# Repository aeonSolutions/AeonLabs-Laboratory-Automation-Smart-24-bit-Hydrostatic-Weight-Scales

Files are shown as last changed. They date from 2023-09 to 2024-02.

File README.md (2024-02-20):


  
 
 

<a href="https://trackgit.com">
trackgit-views
</a>




[](https://www.buymeacoffee.com/migueltomas)

[PCB-Prototyping-Catalogue](https://github.com/aeonSolutions/PCB-Prototyping-Catalogue)  >>  [Laboratory Automation](https://github.com/aeonSolutions/PCB-Prototyping-Catalogue/tree/main/Laboratory%20Automation)  >> Wieght Scales >> Smart 24-bit Hydrostatic Weight Scale

<br>

# 24-bit Smart data Acquisiton SDAD for Weight Measurments

This is a 24-bit S.D.A.D. weight scale capable to do hydrostatic weight measurments up to 20Kg. 

<p align="center">
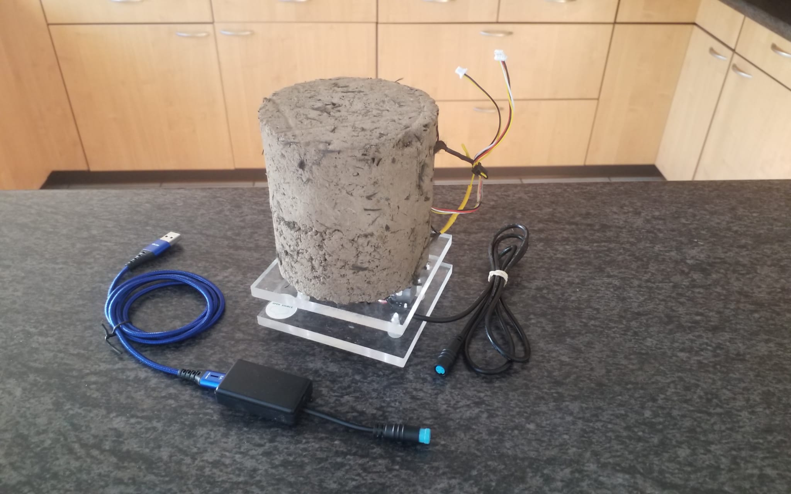
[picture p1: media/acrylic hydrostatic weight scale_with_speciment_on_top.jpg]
    
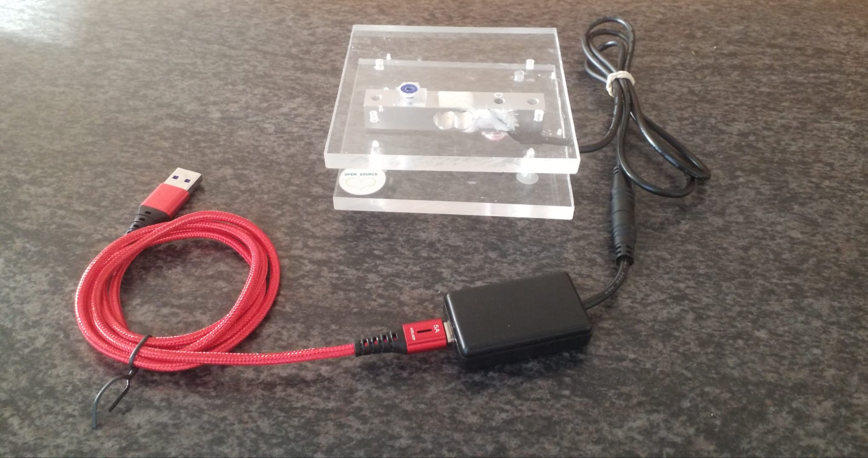
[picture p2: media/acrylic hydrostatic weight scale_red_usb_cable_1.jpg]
     
</p>

<br>

## Parts List
 - [S.D.A.D. hardware electronics](http://www.tindie.com/stores/aeonlabs)
 - [Plexiglass Clear Acrylic Board](https://s.click.aliexpress.com/e/_Ddi8Lh5)
 - [Load Cell HX711 ](https://s.click.aliexpress.com/e/_DBjevT1)
 - [aluminum flat hex socket countersunk head screw size M4 20mm](https://www.aliexpress.com/item/32964202588.html?spm=a2g0o.order_list.order_list_main.4.f3a61802ivrUvG)
 - [aluminum flat hex socket countersunk head screw size M5 20mm](https://www.aliexpress.com/item/32964202588.html?spm=a2g0o.order_list.order_list_main.4.f3a61802ivrUvG)
 - [connector Cable M8 waterproof 4-pin](https://s.click.aliexpress.com/e/_DCR6iBd)
 - [USB-C cable](https://s.click.aliexpress.com/e/_De4Q32X)

<br>

## Compatibility

<p align="center">
 <a href"https://www.apple.com/shop/accessories/all/homekit">

 </a>
<a href="https://home.google.com"> 
 
 </a>
<a href="https://www.home-assistant.io">  
 
 </a>
<a href="https://csa-iot.org/all-solutions/matter/">  
 
 </a>
<a href="https://csa-iot.org/all-solutions/matter/">  
 
 </a>
</p>

<br>

## What one additionally needs
- [USB to UART/USB TTL firmware burner for 5V and 3.3V MCUs ](https://github.com/aeonSolutions/PCB-Prototyping-Catalogue/blob/main/DIY-Maker/README.md)
- [Upgradable ESP32 MCU](https://github.com/aeonSolutions/AeonLabs-Upgradable-MCU-ESP32)

<br />
<br />

**Get a Notification on every PCB update**

| [](https://www.tindie.com/stores/aeonlabs/) | You can fill in your [email here (Google form)](https://docs.google.com/forms/d/e/1FAIpQLScErMgQYRdA-umvCjvTPPrCO7Lg1QYowTxb7vfa8cTfrcPEAA/viewform?usp=pp_url) and I'll send a reminder when a new PCB prototype is made available here or a new revision for an existing PCB. Stay tuned! |
|---|---|

<br>
<br>

## Author

You can get in touch with me on my LinkedIn Profile:

#### Miguel Tomas



You can also follow my GitHub Profile to stay updated about my latest projects: 

**Hire me on Fiverr**

If you like my work here and are looking to design and deploy your own smart device you can hire me on:

- [Fiverr](https://www.fiverr.com/s/GjmPxe). The price starts at $25
- [Guru](https://www.guru.com/freelancers/miguel-tomas)
  
<br>

### Be supportive of my dedication and work towards technology education and buy me a cup of coffee
The PCB Desgin Files i provide here for anyone to use are free. If you like this Smart Device or use it, please consider buying me a cup of coffee, a slice of pizza or a book to help me study, eat and think new PCB design files.

[](https://www.buymeacoffee.com/migueltomas)

<br />

### Make a donation on Paypal
Make a donation on paypal and get a TAX refund*.

(http://paypal.me/mtpsilva)

<br>

### Support all these open hardware projects and become a patreon  
Liked any of my PCB KiCad Designs? Help and Support my open work to all by becomming a LDAD Patreon.
In return I will give a free PCB design in KiCad to all patreon supporters. To learn more go to patreon.com. Link below.

(https://www.patreon.com/ldad)

<br />
<br />

______________________________________________________________________________________________________________________________
### License

Before proceeding to download any of AeonLabs software solutions for open-source development and/or PCB hardware electronics development make sure you are choosing the right license for your project. See [AeonLabs Solutions for Open Hardware & Source Development](https://github.com/aeonSolutions/PCB-Prototyping-Catalogue/wiki/AeonLabs-Solutions-for-Open-Hardware-&-Source-Development) for more information.

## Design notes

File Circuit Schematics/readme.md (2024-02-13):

[PCB-Prototyping-Catalogue](https://github.com/aeonSolutions/PCB-Prototyping-Catalogue)  >>  [Laboratory Automation](https://github.com/aeonSolutions/PCB-Prototyping-Catalogue/tree/main/Laboratory%20Automation)  >> Wieght Scales >> Smart 24-bit Hydrostatic Weight Scale

<div align="right">
 <a href="https://github-com.translate.goog/aeonSolutions/AeonLabs-AI-Volvo-MKII-Open-Hardware/wiki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">Change language</a>  <br>
Last change 15-02-2024
</div>

<br>

This folder contains the circuit schematic for the Smart 24-bit Hydrostatic Weight Scale used on my Open Science projects. Each KiCad project is available with a [creative commons share alike non-commercial license](https://creativecommons.org/licenses/by-nc-sa/4.0/deed.en) . If you like it and use it on your own hardware designs please support this project, [click here](https://github.com/sponsors/aeonSolutions) to learn how. <br> Thank you 🙏. 

### Support all these open hardware projects and become a GitHub sponsor  
Liked any of my PCB KiCad Designs? Help and Support my open work to all by becoming a GitHub sponsor.

<p align="center">
    <a href="">
        
    </a>
    <a href="https://github.com/sponsors/aeonSolutions">
        
    </a>
</p>

#

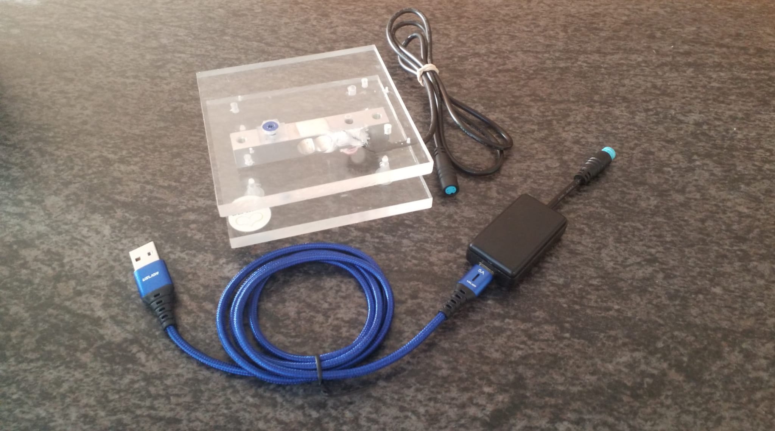
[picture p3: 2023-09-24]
media/acrylic hydrostatic weight scale_3.jpg

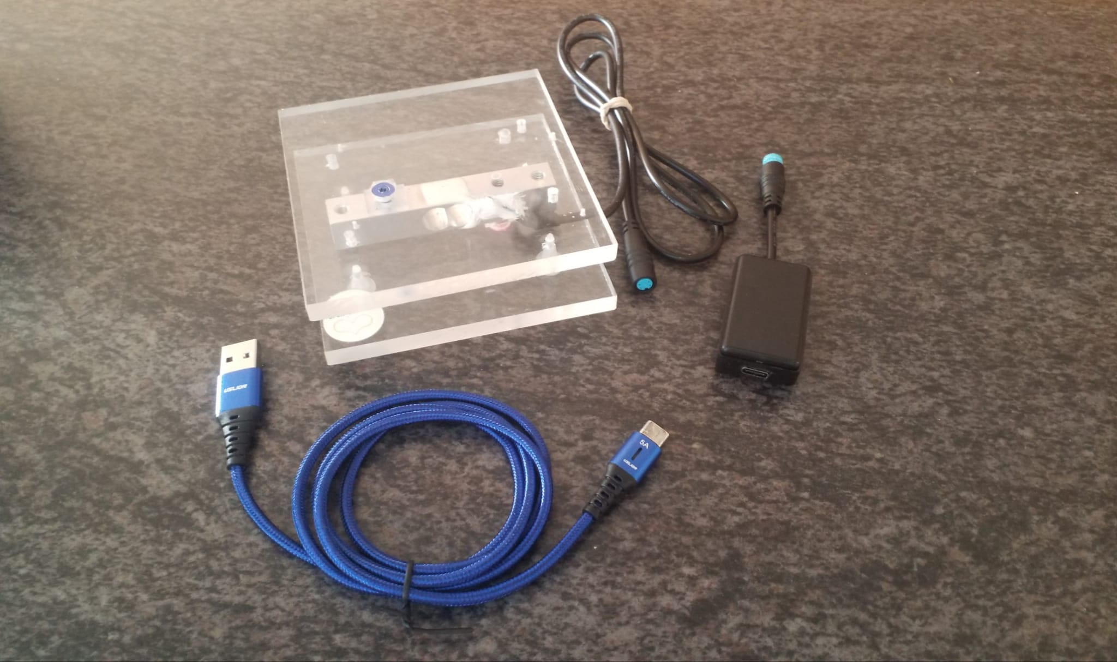
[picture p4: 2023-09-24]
media/acrylic hydrostatic weight scale_2.jpg

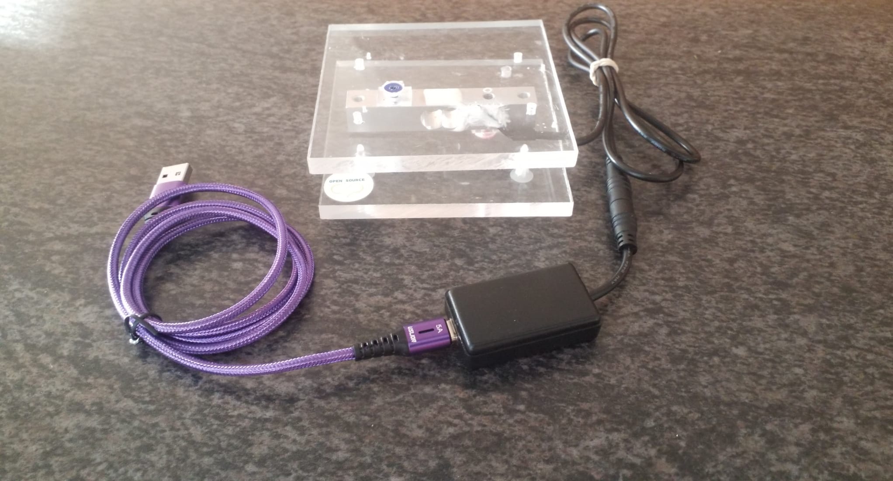
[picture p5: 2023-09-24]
media/acrylic hydrostatic weight scale_violet_usb_cable_1.jpg

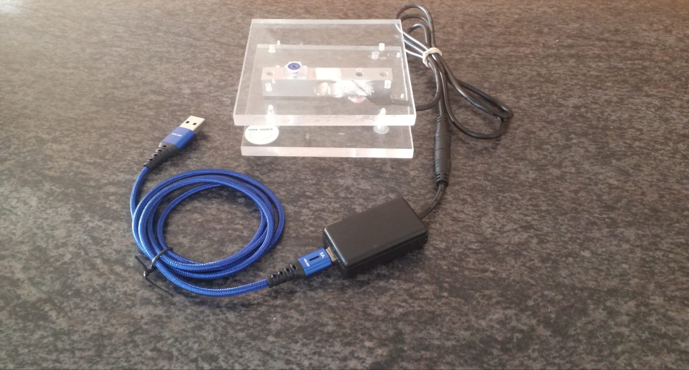
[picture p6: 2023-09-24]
media/acrylic hydrostatic weight scale_4.jpg

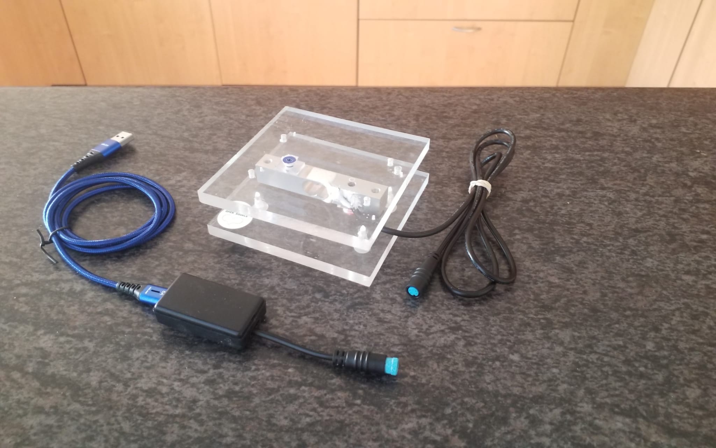
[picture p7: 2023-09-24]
media/acrylic hydrostatic weight scale_1.jpg

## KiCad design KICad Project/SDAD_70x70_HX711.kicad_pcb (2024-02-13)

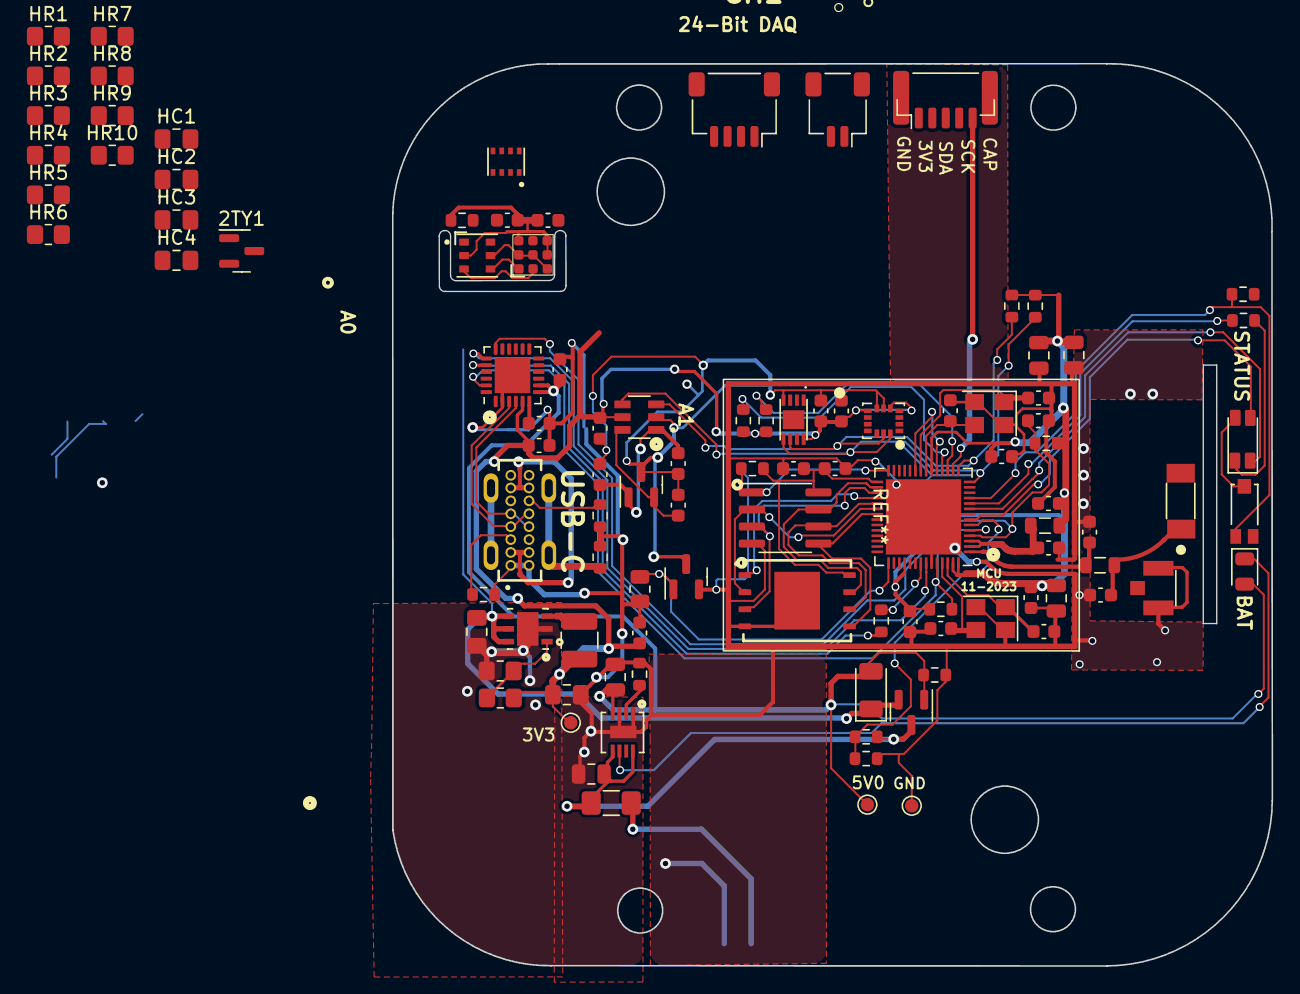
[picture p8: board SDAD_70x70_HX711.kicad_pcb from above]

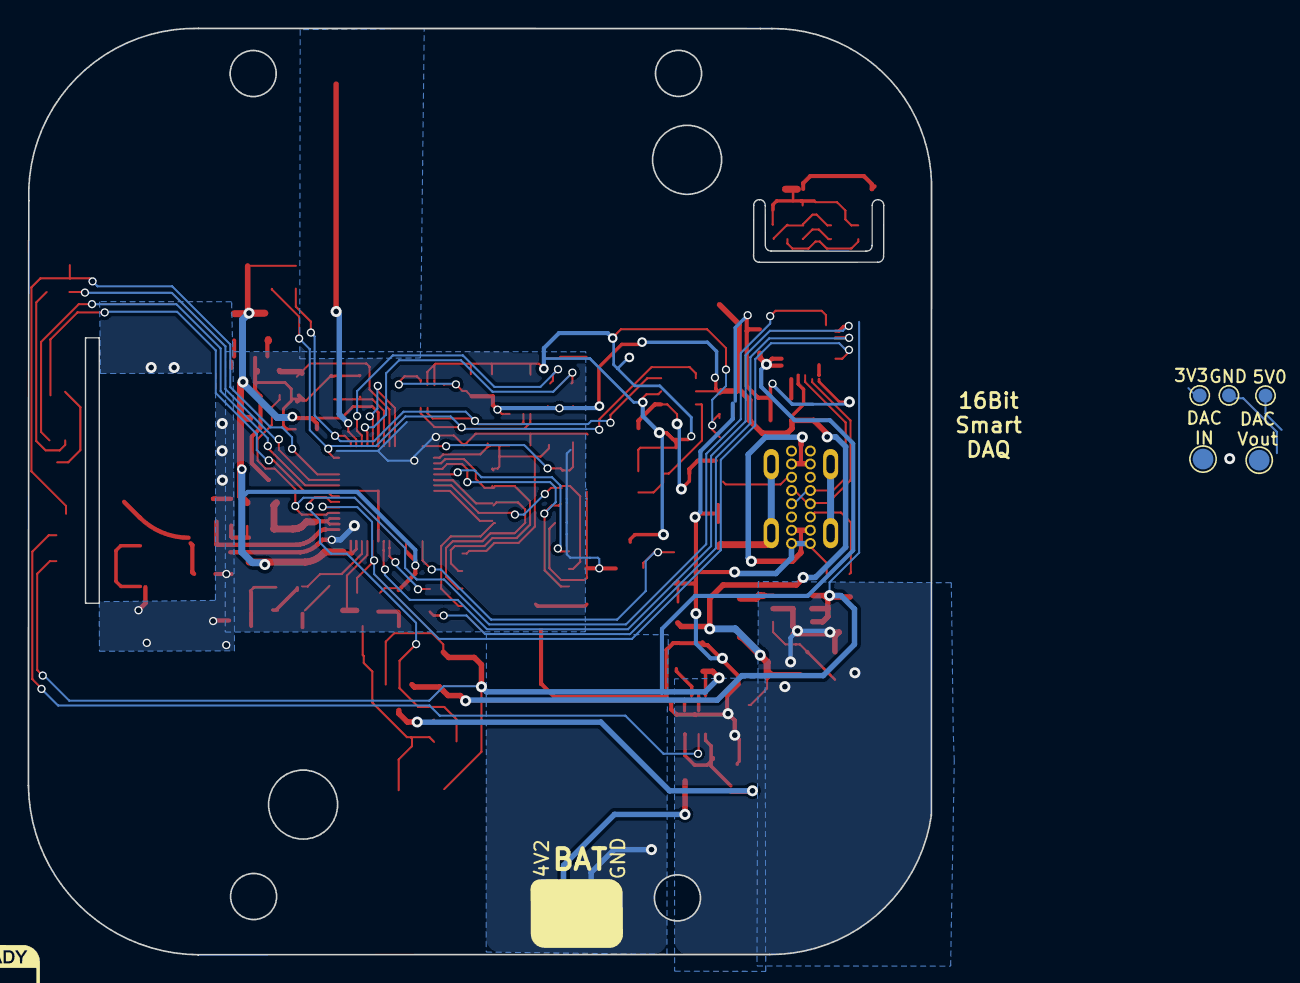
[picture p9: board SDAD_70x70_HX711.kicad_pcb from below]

Board: 2 copper layers, 65.4 x 67.1 mm, 108 parts (4 on the bottom side), 64 nets.

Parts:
2TY1: S8550; SOT-23
ADS1100_CH2: ADS1100A0IDBVR; ADS1100 16-bit ADC SOT95P280X145-6N
ADS1100_CH_C3: 33-100pF; C_0603_1608Metric
ADS1100_CH_C4: 100nF; C_0603_1608Metric
ATSHA_C1: 100nF; C_0603_1608Metric
AUR1: AUR9718x_DFN_3x3mm_6_pin; AUR9718 ST1S09 SON95P300X300X100-7N
AUR_C1: 22uF; C_0805_2012Metric_Pad1.18x1.45mm_HandSolder
AUR_C2: 4.7uF; C_0805_2012Metric_Pad1.18x1.45mm_HandSolder
AUR_R1: 75k; R_0805_2012Metric_Pad1.20x1.40mm_HandSolder
AUR_R2: 24k; R_0805_2012Metric_Pad1.20x1.40mm_HandSolder
AUR_l1: 3.3uF; L_1210_3225Metric
BAT_FUSE1: Polyfuse; Fuse_1206_3216Metric_Pad1.42x1.75mm_HandSolder
BAT_SENSE_R1, BAT_SENSE_R2: 100k; R_0603_1608Metric
BMPR1: 10k; R_0603_1608Metric
CHC1, CHC2, CHC3: 1uF; C_0603_1608Metric
CN3065_C2: 4.7uF; C_0805_2012Metric
CN3065_R1: 1K8; R_0603_1608Metric
CN3065_STDBY_LED1: LED; LED_0805_2012Metric
CN3965_C1: 22uF; C_0805_2012Metric
DMP1045U_1: DMP1045U; SOT-23
DMP1045_R1: 10K; R_0603_1608Metric
DMP1045_SCHOT1: D_Schottky; D_1206_3216Metric
ENS_C1: 1uF; C_0603_1608Metric
ENS_C2: 100nF; C_0603_1608Metric
EPS1: ESP32-PSRAM_LY68L6400S; SOIC-8_3.9x4.9mm_P1.27mm
ESP32S1: ESP32-S3; QFN-56-1EP_7x7mm_P0.4mm_EP5.6x5.6mm
ESP32_SHIELD1: RFShield_OnePiece; ESP32-S3 GND Shield
ESP_FLASH1: W25Q128JVS; WSON8 FLASH SPI SON127P800X600X80-9N
E_DTR_R1: 10k; R_0603_1608Metric
E_LNA_ANT1: AN9520; CrossAir CA-C03
E_LNA_ANT2: U.FL-R-SMT(01); RF Antenna IPEX SMD PCB HRS_U.FL-R-SMT(01)
E_LNA_C1, E_LNA_C2: 2.7pF; C_0603_1608Metric
E_LNA_l1: 1.8nH 5%; L_0805_2012Metric
E_RTS_C1: 100nF; C_0603_1608Metric
E_RTS_R1: 10k; R_0603_1608Metric
E_SPI_C1: 1uF 10% 50V; C_0603_1608Metric
E_SPI_C2: 100nF 10% 16V; C_0603_1608Metric
E_UART_TX_1: 499R; R_0603_1608Metric
E_VDDA_C1: 100nF; C_0603_1608Metric
E_VDDA_C2: 1uF 10% 50V; C_0805_2012Metric
E_VDD_3_C1, E_VDD_3_C2: 10uF 20% 6.3V; C_0805_2012Metric
E_VDD_3_C3, E_VDD_3_C4: 100nF 10% 16V; C_0603_1608Metric
E_VDD_CPU_C1: 100nF 10% 16V; C_0603_1608Metric
E_VDD_L1: 12nH 5%; L_0805_2012Metric
E_VDD_RTC_C1: 100nF 10% 16V; C_0603_1608Metric
E_XTAL32_1: 32.768Mhz 22pF+-10PPM; Crystal_SMD_3225-4Pin_3.2x2.5mm
E_XTAL32_C1, E_XTAL32_C2, E_XTAL40_C1, E_XTAL40_C2: 22pF 5% 50V; C_0603_1608Metric
E_XTAL40_1: 40Mhz 22pF+-10PPM; Crystal_SMD_3225-4Pin_3.2x2.5mm
ExtSWBAT_PLUG2: Conn_01x03_Female; JST_SH_BM03B-SRSS-TB_1x03-1MP_P1.00mm_Vertical
HC1: 10pF; C_0805_2012Metric_Pad1.18x1.45mm_HandSolder
HC2, HC3, HC4: 0.1pF; C_0805_2012Metric_Pad1.18x1.45mm_HandSolder
HR1, HR2, HR9, HR10: 2k2; R_0805_2012Metric_Pad1.20x1.40mm_HandSolder
HR3, HR4, HR7, HR8: 100R; R_0805_2012Metric_Pad1.20x1.40mm_HandSolder
HR5: 18k4; R_0805_2012Metric_Pad1.20x1.40mm_HandSolder
HR6: 8.4k; R_0805_2012Metric_Pad1.20x1.40mm_HandSolder
HXC2: 2.2uF; C_0603_1608Metric
I2C1: I2C6; JST_SH_SM04B-SRSS-TB_1x04-1MP_P1.00mm_Horizontal
I2C_SCL_R2, I2C_SDA_R1, I2C_SDA_R2, I2C_SDA_R2#2: 10k; R_0603_1608Metric
IC_ENS1: ENS160 Gas Semsor
IMU1: LSM6DS3; LSM6DS3 Motion Sensor PQFN50P300X250X86-14N
IMUC1: 100nF; C_0603_1608Metric
J2: USB4120-03-C_REVA; USB-C Vertical GCT_USB4120-03-C_REVA
LED1: LED_GBRC; LED_1206_3210_RGB_Metric
LR1: 330R; R_0603_1608Metric
MTRR1: 10k; R_0805_2012Metric
MTRT1: NPN; SOT-23
PLUG2: PLUG2; JST_SH_BM05B-SRSS-TB_1x05-1MP_P1.00mm_Vertical
PSRAM_R1: 100K; R_0603_1608Metric
PWOUT3V1: Screw_Terminal_01x02; JST_SH_SM02B-SRSS-TB_1x02-1MP_P1.00mm_Horizontal
TMPR1: 10K; R_0603_1608Metric
TP1, TP1#2: VIN; TestPoint_Pad_D1.0mm
TP2, TP2#2: VOut; TestPoint_Pad_D1.0mm
TP3, TP3#2: GND; TestPoint_Pad_D1.0mm
U1: MCP1525-TT; SOT-23
U2: ATSHA204A-MAHDA-T; ATSHA204A-MAHDA-T UDFN-8
U3: Battery_charger_CN3065_QFN8; QFN8 3.1x2.9mm QFNn-8 3x3 SON80P400X400X100-9N
U4: AHT20; AHT20 HT Sensor PSON100P300X300X110-6N
U5: CH9102F
U6: TEMT6000; TEMT6000-SEN
U7: BMP280; XDCR_BMP280
USB_PLUG_R2, USB_PLUG_R4: 5k1; R_0603_1608Metric
USB_PLYG_R1: 150K; R_0603_1608Metric
VOLTAGE_REF_C1, VOLTAGE_REF_C2: 100nF; C_0603_1608Metric

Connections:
3V3: 2TY1.2 (E), ADS1100_CH2.5 (VDD), ADS1100_CH_C4.2, ATSHA_C1.2, AUR_C1.1, AUR_R1.1, AUR_l1.1, BMPR1.2, CHC3.1, ENS_C1.2, ENS_C2.2, ESP32S1.20 (VDD3P3_RTC), ESP32S1.46 (VDD3P3_CPU), ESP32S1.55 (VDDA), ESP32S1.56 (VDDA), E_DTR_R1.1, E_RTS_R1.1, E_VDDA_C1.2, E_VDDA_C2.2, E_VDD_3_C1.1, E_VDD_3_C2.1, E_VDD_3_C3.1, E_VDD_CPU_C1.1, E_VDD_L1.1, E_VDD_RTC_C1.1, HXC2.2, I2C_SCL_R2.1, I2C_SDA_R1.2, I2C_SDA_R2.1, I2C_SDA_R2#2.2, IC_ENS1.4 (VDD), IC_ENS1.5 (VDDIO), IC_ENS1.7 (CS), IMU1.5 (VDDIO), IMU1.8 (VDD), IMUC1.2, LED1.4 (K), PLUG2.2, TP2.1, TP2#2.1, U2.8 (VCC), U4.2 (VDD), U5.5 (VIO), U6.COLLECTOR, U7.6 (VDDIO), U7.8 (VDD)
3V3_PLUG: ADS1100_CH2.1 (VIN+), ADS1100_CH_C3.2, U1.1 (Vin), VOLTAGE_REF_C1.2
A+: HR1.2, HR4.2, I2C1.3
A-: HR2.2, HR3.2, I2C1.4
B+: HR7.2, HR9.2, I2C1.1
B-: HR8.2, HR10.1, I2C1.2
BAT_SENSE_IO21: BAT_SENSE_R1.1, BAT_SENSE_R2.2, ESP32S1.6 (GPIO1/ADC1_CH0)
CAPACITIVE_SENSOR_IO11: ESP32S1.16 (GPIO11/ADC2_CH0), PLUG2.5
CHIP_EN: ESP32S1.4 (CHIP_PU/RESET), E_RTS_C1.2, E_RTS_R1.2, U5.18 (CTS)
DAC_CALIBRATION: ESP32S1.19 (GPIO14/ADC2_CH3), ESP32S1.23 (GPIO17/ADC2_CH6/DAC_2)
ESP_GPIO0_BOOT-DTR: ESP32S1.5 (GPIO0/BOOT), ESP32S1.52 (GPIO46), E_DTR_R1.2, U5.23 (DTR)
GND: AUR1.2 (GND), AUR1.7 (GND), AUR_C1.2, AUR_C2.2, AUR_R2.2, BAT_SENSE_R1.2, CHC1.2, CHC2.1, CHC3.2, CN3065_C2.1, CN3065_R1.1, CN3965_C1.1, DMP1045_R1.2, EPS1.4 (VSS), ESP32S1.8 (GPIO3/ADC1_CH2), ESP32S1.51 (GPIO45), ESP32S1.57 (GND), ESP32_SHIELD1.1 (Shield), ESP_FLASH1.4 (GND), ESP_FLASH1.9 (GND), E_LNA_ANT2.1 (GND), E_LNA_ANT2.2 (GND), E_LNA_C1.2, E_LNA_C2.2, E_RTS_C1.1, E_SPI_C1.2, E_SPI_C2.2, E_VDDA_C1.1, E_VDDA_C2.1, E_VDD_3_C1.2, E_VDD_3_C2.2, E_VDD_3_C3.2, E_VDD_3_C4.2, E_VDD_CPU_C1.2, E_VDD_RTC_C1.2, E_XTAL32_1.2, E_XTAL32_1.4, E_XTAL32_C1.2, E_XTAL32_C2.2, E_XTAL40_1.2, E_XTAL40_1.4, E_XTAL40_C1.2, E_XTAL40_C2.2, ExtSWBAT_PLUG2.3, HC1.1, HC2.2, HR2.1, HR6.2, HR10.2, HXC2.1, J2.A1 (GND_A), J2.A12 (GND_A__1), J2.B1 (GND_B), J2.B12 (GND_B__1), MTRR1.1, MTRT1.2, PWOUT3V1.2, TP3.1, TP3#2.1, U3.1 (V_Temp), U3.3 (GND), U3.9 (GND), U5.0 (GND), U5.2 (GND), USB_PLUG_R2.2, USB_PLUG_R4.2, USB_PLYG_R1.2
GNDD: ADS1100_CH2.2 (GND), ADS1100_CH_C3.1, ADS1100_CH_C4.1, ATSHA_C1.1, ENS_C1.1, ENS_C2.1, IC_ENS1.3 (MISO), IC_ENS1.8 (VSS), IC_ENS1.9 (VSS), IMU1.6 (GND), IMU1.7 (GND), IMUC1.1, MTRT1.3, PLUG2.1, TMPR1.1, U1.3 (Vss), U2.4 (GND), U4.5 (GND), U7.1 (GND), U7.5 (SDO), U7.7 (GND), VOLTAGE_REF_C1.1, VOLTAGE_REF_C2.1
GPIO8_I2C_SDA: ADS1100_CH2.4 (SDA), ESP32S1.14 (GPIO9/ADC1_CH8), I2C_SDA_R1.1, IC_ENS1.1 (SDA), IMU1.14 (SDA), PLUG2.3, U2.5 (SDA), U4.4 (SDA), U7.3 (SDI)
GPIO9_I2C_SCL: ADS1100_CH2.3 (SCL), ESP32S1.15 (GPIO10/ADC1_CH9), I2C_SDA_R2.2, IC_ENS1.2 (SCL), IMU1.13 (SCL), PLUG2.4, U2.6 (SCL), U4.3 (SCL), U7.4 (SCK)
HX3V3: 2TY1.3 (C), HC1.2, HR1.1, HR5.2, HR9.1, PWOUT3V1.1
LCD_I2C_SCL_IO12: ESP32S1.18 (GPIO13/ADC2_CH2), I2C_SCL_R2.2
LCD_I2C_SDA_IO38: ESP32S1.17 (GPIO12/ADC2_CH1), I2C_SDA_R2#2.1
LED_B_IO05: ESP32S1.7 (GPIO2/ADC1_CH1), LED1.2 (BA)
LED_G_IO02: ESP32S1.9 (GPIO4/ADC1_CH3), LED1.1 (GA)
LED_R_IO04: ESP32S1.10 (GPIO5/ADC1_CH4), LR1.1
unnamed: AUR1.1 (FB), AUR_R1.2, AUR_R2.1
unnamed: AUR1.3 (SW), AUR_l1.2
unnamed: ESP32S1.21 (GPIO15/ADC2_CH4/XTAL_32K_P), E_XTAL32_1.3, E_XTAL32_C1.1
unnamed: ESP32S1.22 (GPIO16/ADC2_CH5/XTAL_32K_N), E_XTAL32_1.1, E_XTAL32_C2.1
unnamed: ESP32S1.1 (LNA_IN/RF), E_LNA_C2.1, E_LNA_l1.2
unnamed: ESP32S1.49 (U0TXD/PROG/GPIO43), E_UART_TX_1.2
unnamed: ESP32S1.2 (VDD3P3), ESP32S1.3 (VDD3P3), E_VDD_3_C4.1, E_VDD_L1.2
unnamed: ESP32S1.53 (XTAL_N), E_XTAL40_1.3, E_XTAL40_C2.1
unnamed: ESP32S1.54 (XTAL_P), E_XTAL40_1.1, E_XTAL40_C1.1
unnamed: E_LNA_ANT1.1, E_LNA_C1.1, E_LNA_l1.1
unnamed: HC3.2, HR4.1
unnamed: HC3.1, HR3.1
unnamed: HC4.2, HR7.1
unnamed: HC4.1, HR8.1
unnamed: HR5.1, HR6.1
unnamed: J2.A5 (CC1), USB_PLUG_R2.1
unnamed: J2.B5 (CC2), USB_PLUG_R4.1
unnamed: J2.S1 (SHIELD), USB_PLYG_R1.1
unnamed: LED1.3 (RA), LR1.2
unnamed: CN3065_R1.2, U3.2 (I_SET)
unnamed: CHC2.2, U5.6 (V3)
unnamed: BMPR1.1, U7.2 (CSB)
PERIPHERALS_PWR_EN_IO38: ESP32S1.43 (GPIO38), MTRR1.2, MTRT1.1
RXD0: ESP32S1.50 (U0RXD/PROG/GPIO44), U5.19 (RTS)
SPICLK: EPS1.6 (SCLK), ESP32S1.33 (SPICLK/GPIO30), ESP_FLASH1.6 (CLK)
SPICS0: ESP32S1.32 (SPICS0/GPIO29), ESP_FLASH1.1 (~CS)
SPICS1: EPS1.1 (~CE), ESP32S1.28 (SPI_CS1/GPIO26), PSRAM_R1.1
SPID: EPS1.5 (SiO0), ESP32S1.35 (SPID/GPIO32), ESP_FLASH1.5 (DI(IO0))
SPIHD: EPS1.7 (SIO3), ESP32S1.30 (SPIHD/GPIO27), ESP_FLASH1.7 (IO3)
SPIQ: EPS1.2 (SIO1), ESP32S1.34 (SPIQ/GPIO31), ESP_FLASH1.2 (DO(IO1))
SPIWP: EPS1.3 (SIO2), ESP32S1.31 (SPIWP/GPIO28), ESP_FLASH1.3 (IO2)
STDBY_LED_G: CN3065_STDBY_LED1.1 (K), U3.6 (LED_DONE)
TEMT6000_IO33: ESP32S1.11 (GPIO6/ADC1_CH5), TMPR1.2, U6.EMITTER
TXD0: E_UART_TX_1.1, U5.20 (RXD)
USB_5V0: CHC1.1, CN3065_STDBY_LED1.2 (A), CN3965_C1.2, DMP1045U_1.1, DMP1045_R1.1, DMP1045_SCHOT1.2 (A), TP1.1, U3.4 (VIN), U5.7 (VDD5), U5.8 (VBUS)
USB_5V0F: J2.A4 (VBUS_A), J2.A9 (VBUS_A__1), J2.B4 (VBUS_B), J2.B9 (VBUS_B__1)
USB_D+: J2.A6 (D1+), J2.B6 (D2+), U5.3 (D+)
USB_D-: J2.A7 (D1-), J2.B7 (D2-), U5.4 (D-)
VDD_SPI: EPS1.8 (VCC), ESP32S1.29 (VDD_SPI), ESP_FLASH1.8 (VCC), E_SPI_C1.1, E_SPI_C2.1, PSRAM_R1.2
VIN: AUR1.4 (VIN_SW), AUR1.5 (VIN_A), AUR1.6 (EN), AUR_C2.1, DMP1045U_1.2, DMP1045_SCHOT1.1 (K), TP1#2.1
VIN_BAT: BAT_FUSE1.1, BAT_SENSE_R2.1, CN3065_C2.2, DMP1045U_1.3, U3.5 (BAT+), U3.8 (FB)
VIN_BATF: BAT_FUSE1.2, ExtSWBAT_PLUG2.1
VOLTAGE_REF_2.5V: ADS1100_CH2.6 (VIN-), U1.2 (Vout), VOLTAGE_REF_C2.2

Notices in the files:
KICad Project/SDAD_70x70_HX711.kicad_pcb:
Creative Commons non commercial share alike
